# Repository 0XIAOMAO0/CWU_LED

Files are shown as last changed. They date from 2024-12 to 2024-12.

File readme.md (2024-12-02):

## 图片









## 项目简介

1. 为了给电池腾出空间因此，板子设计得很紧凑 **焊接难度较大**
2. 打样需要注意 <span style="color:#FF0000">要选板厚1mm</span>
3. 充电部分默认设置了需要外接NTC电阻焊接位置如图所示，不需要的需要将配置电子改为51K 

 

4. 由于底部铝合金可能会导电因此需要垫上0.2mm的导热硅胶垫
5. 预留有两路NTC可供选择焊接，默认关闭了NTC采样与电压检测

## 开源地址
软件地址:https://github.com/0XIAOMAO0/CWU_LED/
硬件地址：https://oshwhub.com/xaiomao/lv-he-jin-bu-guang-deng/

视频链接：https://www.bilibili.com/video/BV1yizGYLE5U/?share_source=copy_web&vd_source=d128331ee99153cf5294c26aba5f51e4

## 材料清单

1. 大部分电子元件芯片都能在优信电子买到（电位器为插件需要将掰一下）重点说明其他零件
2. 均光板 视频中为0.8mm
3. led灯珠冷暖灯珠各28颗8颗紫光灯（2835封装）
4. 小头螺丝m3*6头径5.2,平头螺丝m3*4,圆形铜柱M3*6
5. 背部磁铁8*1mm,0.5mm*4mm(两片厚度不大于1.6mm即可）
6. 0.3mm导热垫，100*100mm一片￥1可铺在灯板与pcb底下（必须）
7. 一共3片CNC

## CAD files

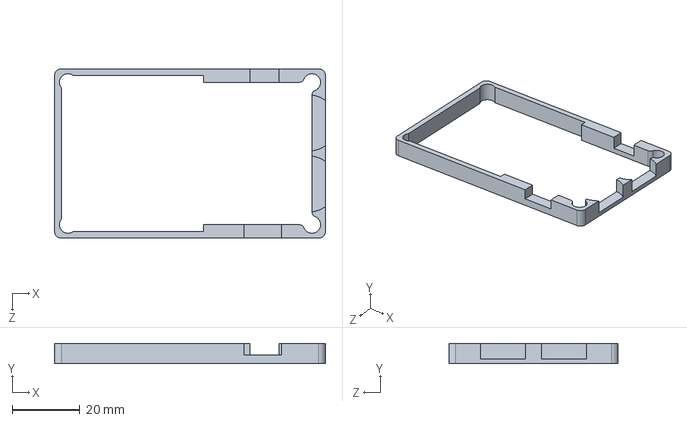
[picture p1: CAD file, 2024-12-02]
model/STEP/中框.STEP
80.0 x 6.00 x 50.0 mm

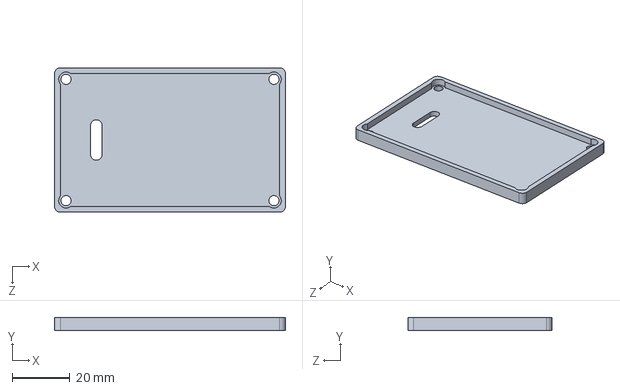
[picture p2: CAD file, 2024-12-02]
model/STEP/顶盖.STEP
80.0 x 4.50 x 50.0 mm

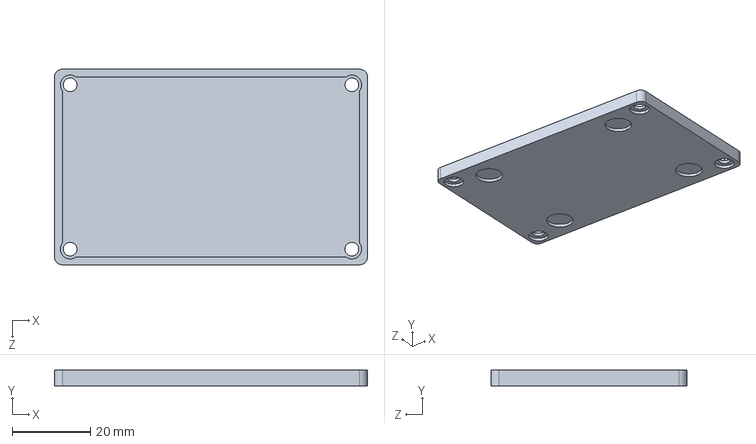
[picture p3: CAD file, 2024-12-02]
model/STEP/底板.STEP
80.0 x 4.00 x 50.0 mm

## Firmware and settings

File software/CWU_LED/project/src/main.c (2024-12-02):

/* add user code begin Header */
/**
  **************************************************************************
  * @file     main.c
  * @brief    main program
  **************************************************************************
  *                       Copyright notice & Disclaimer
  *
  * The software Board Support Package (BSP) that is made available to
  * download from Artery official website is the copyrighted work of Artery.
  * Artery authorizes customers to use, copy, and distribute the BSP
  * software and its related documentation for the purpose of design and
  * development in conjunction with Artery microcontrollers. Use of the
  * software is governed by this copyright notice and the following disclaimer.
  *
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
  **************************************************************************
  */
/* add user code end Header */

/* Includes ------------------------------------------------------------------*/
#include "at32f421_wk_config.h"
#include "wk_adc.h"
#include "wk_exint.h"
#include "wk_tmr.h"
#include "wk_dma.h"
#include "wk_gpio.h"
#include "wk_system.h"

/* private includes ----------------------------------------------------------*/
/* add user code begin private includes */

/* add user code end private includes */

/* private typedef -----------------------------------------------------------*/
/* add user code begin private typedef */
uint16_t get_adcval(adc_channel_select_type adc_channel);  
uint16_t adc_buff[ADC_BUFF_SIZE];
/* add user code end private typedef */

/* private define ------------------------------------------------------------*/
/* add user code begin private define */

/* add user code end private define */

/* private macro -------------------------------------------------------------*/
/* add user code begin private macro */

/* add user code end private macro */

/* private variables ---------------------------------------------------------*/
/* add user code begin private variables */

/* add user code end private variables */

/* private function prototypes --------------------------------------------*/
/* add user code begin function prototypes */

/* add user code end function prototypes */

/* private user code ---------------------------------------------------------*/
/* add user code begin 0 */

/* add user code end 0 */

/**
  * @brief main function.
  * @param  none
  * @retval none
  */
int main(void)
{
  /* add user code begin 1 */

  /* add user code end 1 */

  /* system clock config. */
  wk_system_clock_config();

  /* config periph clock. */
  wk_periph_clock_config();

  /* nvic config. */
  wk_nvic_config();

  /* timebase config. */
  wk_timebase_init();

  /* init dma1 channel1 */
  wk_dma1_channel1_init();
  /* config dma channel transfer parameter */
  /* user need to modify define values DMAx_CHANNELy_XXX_BASE_ADDR and DMAx_CHANNELy_BUFFER_SIZE in at32xxx_wk_config.h */
  wk_dma_channel_config(DMA1_CHANNEL1, 
                        (uint32_t)&ADC1->odt, 
                        DMA1_CHANNEL1_MEMORY_BASE_ADDR, 
                        DMA1_CHANNEL1_BUFFER_SIZE);
  dma_channel_enable(DMA1_CHANNEL1, TRUE);

  /* init adc1 function. */
  wk_adc1_init();

  /* init exint function. */
  wk_exint_config();

  /* init gpio function. */
  wk_gpio_config();

  /* init tmr1 function. */
  wk_tmr1_init();

  /* init tmr3 function. */
  wk_tmr3_init();

  /* add user code begin 2 */
  adc_ordinary_software_trigger_enable(ADC1, TRUE);
  /* add user code end 2 */

  while(1)
  {
    /* add user code begin 3 */
    cwu_pwm_set();
    // cwu_vbat_monitor();
    cwu_temperature_monitor();
    wk_delay_ms(100);
    /* add user code end 3 */
  }
}

  /* add user code begin 4 */

  /* add user code end 4 */

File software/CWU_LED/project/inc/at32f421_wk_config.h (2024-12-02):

/* add user code begin Header */
/**
  **************************************************************************
  * @file     at32f421_wk_config.h
  * @brief    header file of work bench config
  **************************************************************************
  *                       Copyright notice & Disclaimer
  *
  * The software Board Support Package (BSP) that is made available to
  * download from Artery official website is the copyrighted work of Artery.
  * Artery authorizes customers to use, copy, and distribute the BSP
  * software and its related documentation for the purpose of design and
  * development in conjunction with Artery microcontrollers. Use of the
  * software is governed by this copyright notice and the following disclaimer.
  *
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
  **************************************************************************
  */
/* add user code end Header */

/* define to prevent recursive inclusion -----------------------------------*/
#ifndef __AT32F421_WK_CONFIG_H
#define __AT32F421_WK_CONFIG_H

#ifdef __cplusplus
extern "C" {
#endif

/* includes -----------------------------------------------------------------------*/
#include "at32f421.h"

/* private includes -------------------------------------------------------------*/
/* add user code begin private includes */
#include "cwu_led.h"
#include "wk_system.h"
/* add user code end private includes */

/* exported types -------------------------------------------------------------*/
/* add user code begin exported types */
#define ADC_BUFF_SIZE 5
extern uint16_t adc_buff[ADC_BUFF_SIZE];
/* add user code end exported types */

/* exported constants --------------------------------------------------------*/
/* add user code begin exported constants */

/* add user code end exported constants */

/* exported macro ------------------------------------------------------------*/
/* add user code begin exported macro */

/* add user code end exported macro */

/* add user code begin dma define */
/* user can only modify the dma define value */
#define DMA1_CHANNEL1_BUFFER_SIZE   ADC_BUFF_SIZE
#define DMA1_CHANNEL1_MEMORY_BASE_ADDR   (uint32_t)(&adc_buff)
//#define DMA1_CHANNEL1_PERIPHERAL_BASE_ADDR  0

//#define DMA1_CHANNEL2_BUFFER_SIZE   0
//#define DMA1_CHANNEL2_MEMORY_BASE_ADDR   0
//#define DMA1_CHANNEL2_PERIPHERAL_BASE_ADDR   0

//#define DMA1_CHANNEL3_BUFFER_SIZE   0
//#define DMA1_CHANNEL3_MEMORY_BASE_ADDR   0
//#define DMA1_CHANNEL3_PERIPHERAL_BASE_ADDR   0

//#define DMA1_CHANNEL4_BUFFER_SIZE   0
//#define DMA1_CHANNEL4_MEMORY_BASE_ADDR   0
//#define DMA1_CHANNEL4_PERIPHERAL_BASE_ADDR   0

//#define DMA1_CHANNEL5_BUFFER_SIZE   0
//#define DMA1_CHANNEL5_MEMORY_BASE_ADDR   0
//#define DMA1_CHANNEL5_PERIPHERAL_BASE_ADDR   0
/* add user code end dma define */

/* Private defines -------------------------------------------------------------*/
#define ADC_COL_TMP_PIN    GPIO_PINS_0
#define ADC_COL_TMP_GPIO_PORT    GPIOA
#define ADC_NTC1_PIN    GPIO_PINS_6
#define ADC_NTC1_GPIO_PORT    GPIOA
#define ADC_NTC2_PIN    GPIO_PINS_7
#define ADC_NTC2_GPIO_PORT    GPIOA
#define ADC_BAT_PIN    GPIO_PINS_1
#define ADC_BAT_GPIO_PORT    GPIOB
#define ADC_LUM_PIN    GPIO_PINS_2
#define ADC_LUM_GPIO_PORT    GPIOB
#define OPT_PIN    GPIO_PINS_9
#define OPT_GPIO_PORT    GPIOA
#define KEY_PIN    GPIO_PINS_11
#define KEY_GPIO_PORT    GPIOA

/* exported functions ------------------------------------------------------- */
  /* system clock config. */
  void wk_system_clock_config(void);

  /* config periph clock. */
  void wk_periph_clock_config(void);

  /* nvic config. */
  void wk_nvic_config(void);

/* add user code begin exported functions */

/* add user code end exported functions */

#ifdef __cplusplus
}
#endif

#endif
